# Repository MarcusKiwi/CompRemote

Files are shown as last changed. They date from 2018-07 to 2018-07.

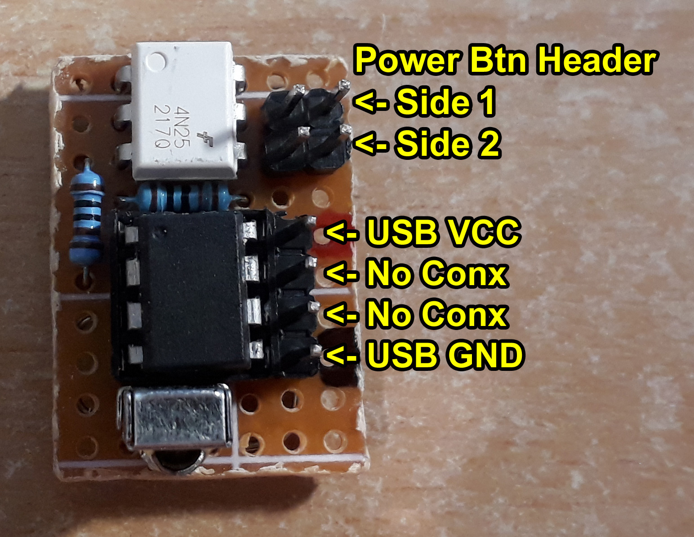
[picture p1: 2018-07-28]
images/pinout.jpg

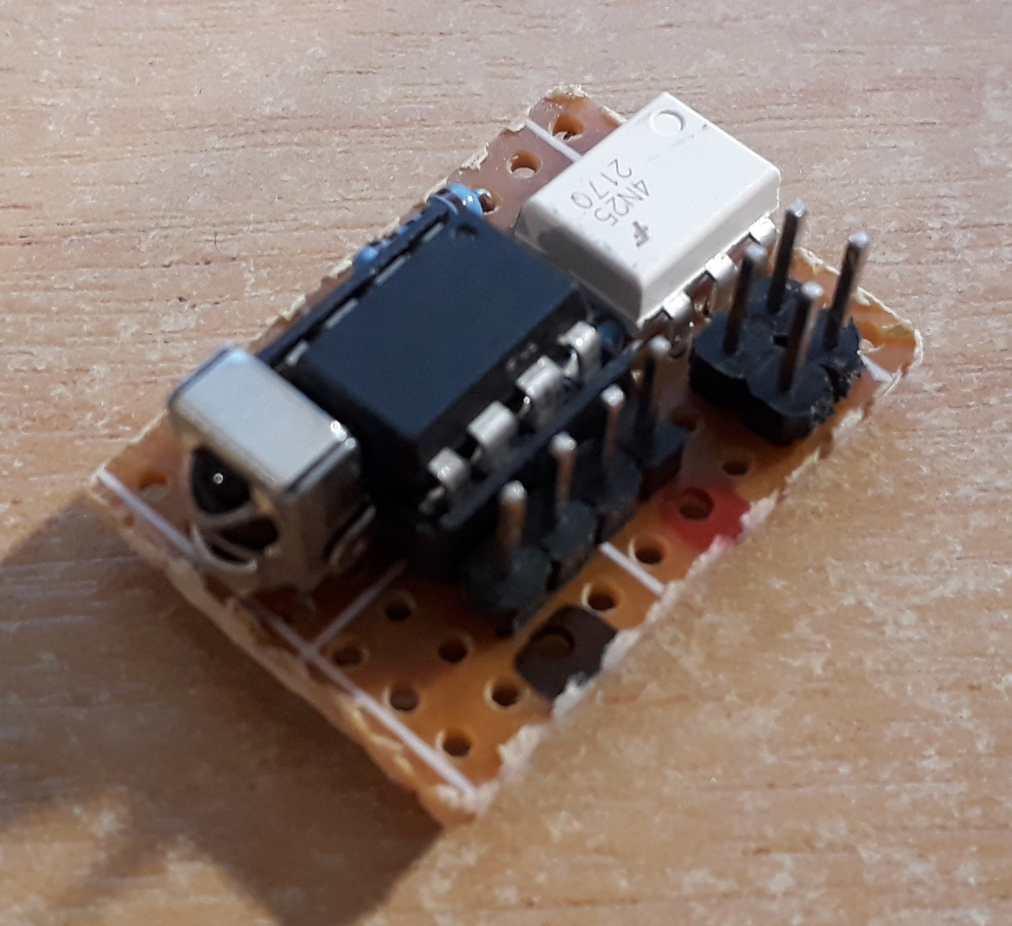
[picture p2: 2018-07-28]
images/front.jpg

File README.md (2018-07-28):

# CompRemote

Device that lets you turn on a desktop computer using a Samsung TV remote.
Is set up to recognize the red teletext button.

This device works alongside your existing case power button, it does not replace it.
Your existing power button will still work.
The device plugs into the motherboards power button header.
Your cases power button plugs into the device instead of the motherboard.

It's powered off of a standard USB2 motherboard pin header.
On most motherboards this header will still be powered when the PC is off.
The device still needs power when the PC is off so it can listen for button presses from a remote, to turn the PC on.

# Components

Full schematics and board layout files are included in KiCad format.

* ATtiny85
* 4N25 OptoIsolator
* VS1838B Infrared Reciever
* 10k Resistor
* 1k Resistor
* Standard header strips

# Software Build Instructions

You don't have to rebuild the project, there is a precompiled CompRemote.hex you can flash with avrdude.

Download this project and [AVR-Libs](https://github.com/MarcusKiwi/AVR-Libs). Recreate this folder structure:

```
base
├───AVR-Libs
│   └───project files
└───CompRemote
    └───project files
```

Run `make` from inside the CompRemote folder to build the HEX file.

Run `make install` to build it and flash to an AVR. The default programmer type is usbasp. This can be reconfigured in the file `base/AVR-Libs/makefile`.

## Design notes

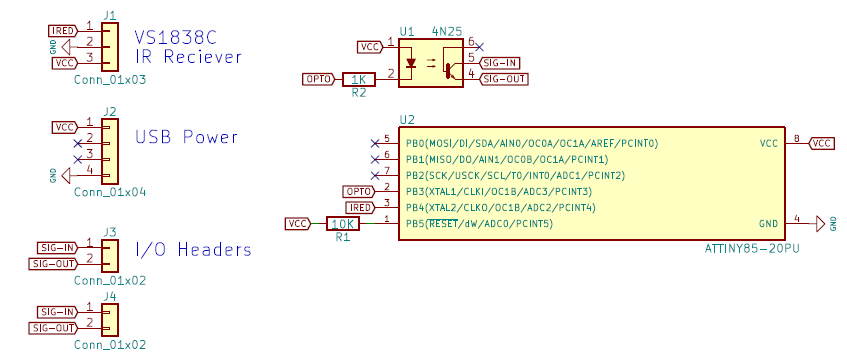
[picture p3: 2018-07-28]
images/schematic.png

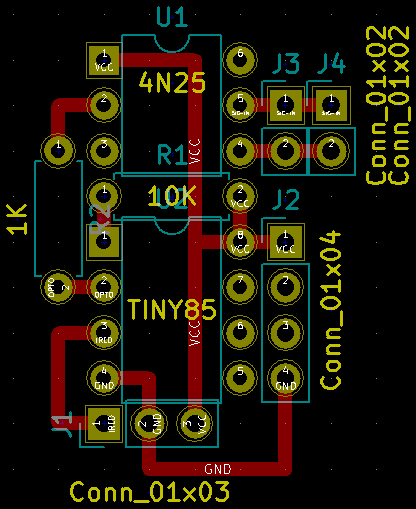
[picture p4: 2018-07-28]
images/board.png

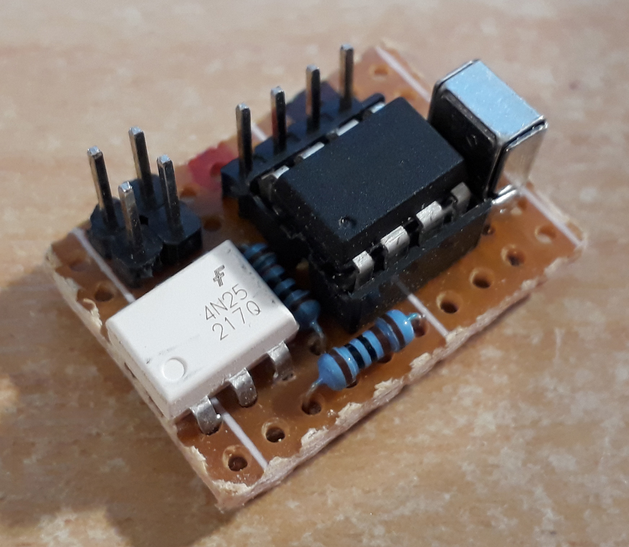
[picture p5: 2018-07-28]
images/back.jpg

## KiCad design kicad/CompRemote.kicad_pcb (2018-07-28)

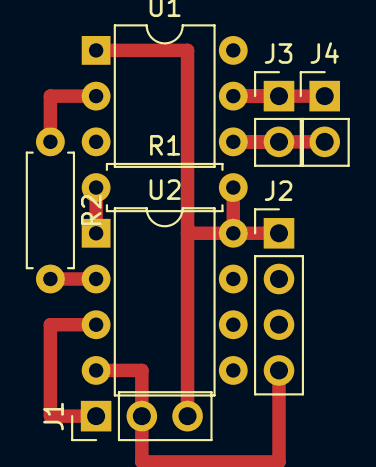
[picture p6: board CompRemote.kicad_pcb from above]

Board: 2 copper layers, 8 parts (0 on the bottom side), 8 nets.

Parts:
J1: Conn_01x03; Pin_Header_Straight_1x03_Pitch2.54mm
J2: Conn_01x04; Pin_Header_Straight_1x04_Pitch2.54mm
J3, J4: Conn_01x02; Pin_Header_Straight_1x02_Pitch2.54mm
R1: 10K; R_Axial_DIN0207_L6.3mm_D2.5mm_P7.62mm_Horizontal
R2: 1K; R_Axial_DIN0207_L6.3mm_D2.5mm_P7.62mm_Horizontal
U1: 4N25; DIP-6_W7.62mm
U2: TINY85; DIP-8_W7.62mm

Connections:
GND: J1.2, J2.4, U2.4
IRED: J1.1, U2.3
unnamed: R1.1, U2.1
unnamed: R2.1, U1.2
OPTO: R2.2, U2.2
SIG-IN: J3.1, J4.1, U1.5
SIG-OUT: J3.2, J4.2, U1.4
VCC: J1.3, J2.1, R1.2, U1.1, U2.8

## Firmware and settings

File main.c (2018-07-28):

#include <avr/io.h>
#include <util/delay.h>

// pins
#define IRED 4
#define OPTO 3

// remote codes
#define REM1 0xE0
#define REM2 0xE0
#define REM3 0x36
#define REM4 0xC9

// stages
#define STRT_LO 0
#define STRT_HI 1
#define DATA_LO 2
#define DATA_HI 3

// vars
uint8_t read = 0;
uint8_t last = 0;
uint8_t count = 0;
uint8_t stg = STRT_LO;
uint8_t signal[4] = {0,0,0,0};
uint8_t pos = 0;
uint8_t bit = 0;

void main() {
	DDRB = (0x00 | (1<<OPTO)); // all input except opto port
	PORTB = (0x00 | (1<<OPTO)); // all low by default except opto port
	while(1) {
		// delay between pulses
		_delay_us(27);
		// check signal
		read = PINB & (1<<IRED);
		// same signal
		if(read==last) {
			count++;
		// signal changed
		} else {
			// intermediate stgs
			if(((stg==STRT_LO)&&(last==0)&&(count>90)&&(count<110)) ||
			   ((stg==STRT_HI)&&(last!=0)&&(count>90)&&(count<110)) ||
			   ((stg==DATA_LO)&&(last==0)&&(count> 9)&&(count< 18)) ) {
				stg++;
			// data
			} else if((stg==DATA_HI)&&(last!=0)&& ( ((count>9)&&(count<18)) || ((count>33)&&(count<45)) ) ) {
				stg=DATA_LO;
				// append data to signal buffer
				signal[pos] = (signal[pos]<<1);
				if((count>33)&&(count<45)) signal[pos] = signal[pos] | 0x01;
				// advance signal counter
				bit++;
				if(bit==8) {
					bit = 0;
					pos++;
					// sequence finished
					if(pos==4) {
						if((signal[0]==REM1)&&(signal[1]==REM2)&&(signal[2]==REM3)&&(signal[3]==REM4)) {
							PORTB &= ~(1<<OPTO); // output lo, opto on
							_delay_ms(125);
							PORTB |= (1<<OPTO); // output hi, opto off
							_delay_ms(625);
						}
						stg = 0;
						pos = 0;
					}
				}
			// corrupt data
			} else {
				stg = 0;
				bit = 0;
				pos = 0;
			}
			// change signal type reset counter
			last = read;
			count = 0;
		}
	}
}
